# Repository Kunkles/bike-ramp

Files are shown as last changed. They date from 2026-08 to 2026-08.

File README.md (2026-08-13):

# Little Ripper — Ramp Generator

**→ [Open the generator](https://kunkles.github.io/bike-ramp/)**

Printable ramps for a toddler on a balance bike — a roller hill, a step drop, or
a little curved jump — split into tiles that fit your printer bed and lock
together with drop-in dovetails.

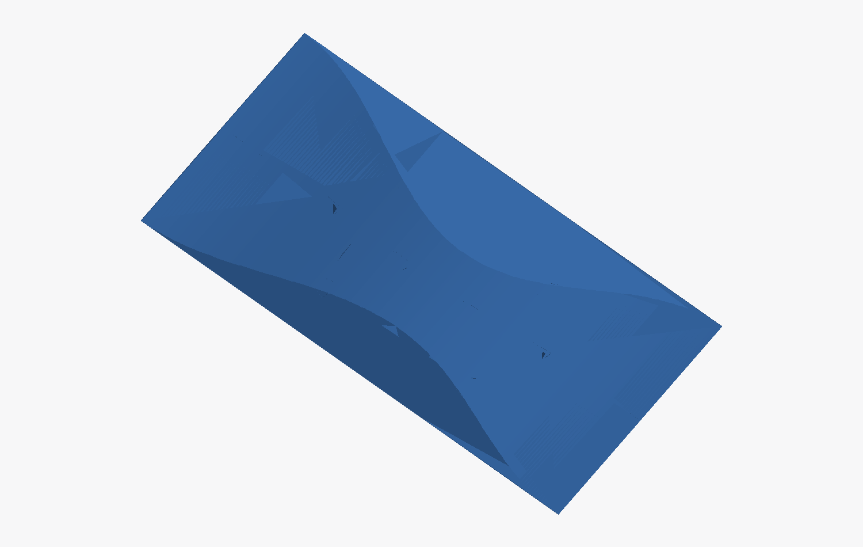
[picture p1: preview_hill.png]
assembled


**Default hill:** 600 mm long × 300 mm wide × 45 mm tall, max slope **12.9°**.
6 tiles, largest 212 × 162 × 45 mm, plus 6 screw-in ground spikes. Roughly
**1.1 kg** of filament.

The profile has zero slope at both toes and at the crest, so there is no edge to
catch a wheel and no kick at the top — he rolls on, over, and off. The outer
90 mm of each side tapers to the floor, so riding off the side is a slope rather
than a drop.

## Files

| | |
|---|---|
| `webapp/coasting-hill.html` | **the generator** — sliders, live 3D, downloads the STLs as a zip |
| `webapp/style.css` | the look: late-80s freestyle BMX, Haro teal and hot magenta |
| `bikeramp.scad` | the same model in OpenSCAD; every dimension is a parameter at the top |
| `render.sh` | exports all tiles to `stl/` |
| `stl/tile_IJ.stl` | the default hill **without** spike sockets — also the test fixture. `I` = position along the run (0…2), `J` = across the width (0…1) |
| `docs/index.html` | the same app as a standalone page, served by GitHub Pages |
| `testplate/` | a one-plate test print with full-size joints — do this first |
| `stlinfo.py` | bounding box + filament estimate for exported STLs |
| `preview.py` | renders the STLs to a PNG |
| `webapp/geom.js` | the model reimplemented as a mesh generator, shared by the app and the tests |
| `webapp/test.js` | checks the mesher against OpenSCAD and proves every tile is watertight |
| `webapp/build.py` | inlines everything into the single-file app |

## The generator

Live at **[kunkles.github.io/bike-ramp](https://kunkles.github.io/bike-ramp/)**,
or open `docs/index.html` straight from disk — it is one self-contained file
with no dependencies, no server and no install. Pick your printer from the
dropdown, drag the sliders, and it
re-tiles live — showing tile count, largest tile against your bed, max slope,
filament and print time — then hands you a zip of STLs plus a README and a
matching `.scad`.

```bash
open webapp/coasting-hill.html
```

Rebuild it after editing anything under `webapp/`:

```bash
python3 webapp/build.py
```

## Or straight from OpenSCAD

STLs for the default hill are already in `stl/`. To re-render with changes:

```bash
./render.sh -D hill_height=70 -D hill_length=800
```

## Print the test plate first

[`testplate/`](testplate/) is a 180 × 160 × 30 mm hill that splits into two
tiles fitting a **single plate** — ~163 g, about 5 h. It is small but nothing on
it is scaled: the dovetail and thread clearances are the production values, so
it answers the two questions that actually matter before you commit a day of
printing. Does a tile drop onto its neighbour, and does a spike wind into its
socket? See [testplate/README.md](testplate/README.md).

## Printing

Six plates, one tile each. **Slice `tile_10.stl` first** — it's the tallest and
most expensive; its real time and weight tell you what the whole set costs.

| Setting | Value |
|---|---|
| Material | **PLA indoors. PETG or ASA if it ever lives in a garage, car, or sun** |
| Layer height | 0.28 mm (0.4 nozzle) |
| Wall loops | 3 |
| Top / bottom shells | **10 top**, 4 bottom |
| Infill | **25% gyroid** |
| Supports | none — every tile prints flat side down, no overhangs |
| Brim | yes, ~5 mm |

**Why 10 top layers and 25% infill.** The low end of the ramp is a nearly flat
surface sitting over sparse infill, which is the classic case for pinholes in
the top skin — it sags between infill lines before it closes. This is a slicing
symptom, not a hole in the model: the mesh there is solid and closed. 25% infill
puts a support roughly every 1.7 mm instead of 2.8 mm, and 10 top layers give
the skin 2.8 mm to close in. Turn on *Ensure vertical shell thickness* as well.
If it still shows, drop to 0.2 mm layers — the surface is shallow, so thinner
layers put far more material under the skin per millimetre of run.

Raising **Toe thickness** does *not* fix this, and slightly works against it: a
thicker toe shrinks the zone that is thin enough to print 100% solid, exposing
more of the shallow curve to sparse infill. It is there for edge durability.

The PLA warning is the one that matters. PLA starts going soft around 55–60 °C
and a hill sitting in a sunny garage or the back of a car will sag out of shape.
Indoors it's fine.

Why those shells: a 15 kg kid plus bike landing on one wheel is roughly 250 N on
a contact patch around 150 mm², about 1.7 MPa. Gyroid at 15% carries that with
around 4× margin, and 6 top layers (1.7 mm) keeps the surface from dimpling
between infill cells. Dropping to 10% infill saves ~150 g and is still fine for
a toddler; go to 20% if he's on the bigger side or you want it to survive adults
standing on it.

Print time is extruded volume divided by an average throughput, plus 6 minutes
a plate for heat-up, levelling and purge. That throughput is the one number
carrying your printer, and the app sets it from whichever you pick — roughly
11 mm³/s for an X1C, 12 for an H2S, 8 for a MK4, 4 for a stock Ender 3. So the
default hill lands near 26 h on an X1C, 22 h on an H2S and 71 h on an Ender 3.

Those are class figures, not measurements. **Slice one plate, then nudge
*Average flow* until the app's time matches** — every later estimate follows
from it.

## Assembly

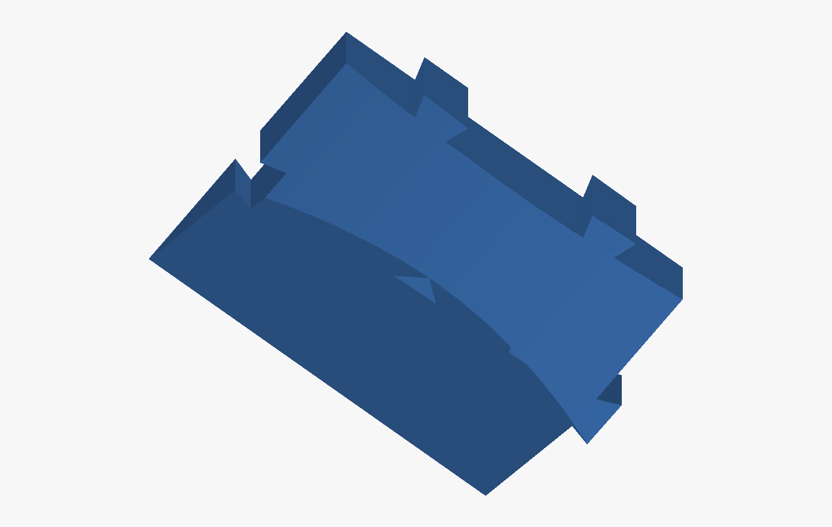
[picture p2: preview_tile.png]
tile


Tiles drop straight down into place; the dovetails are plan-view only, so any
tile can go in at any time and nothing needs sliding. Lay them out 3 along the
run × 2 across, matching the `tile_IJ` numbering, and press the seams together.
Sockets are cut with **0.20 mm** clearance per side, so 0.4 mm of play across
each dovetail. These are plan-view joints — assembly is straight down and the
flanks never slide against each other — so the clearance is there to absorb
print error, mostly first-layer squish on the tab, not to make the parts go
together. 0.35 mm proved loose enough to rattle on a test print.

If a joint binds, a pass with a knife on the socket walls is quicker than
reprinting, and turning on elephant-foot compensation helps. If it still
rattles, drop to 0.15 mm.

Label each tile as it comes off the plate. They all look similar and only one
arrangement is right.

**Stop it sliding.** The dovetails hold tiles to each other, but the assembly as
a whole will skate on a hard floor when he rides at it, and that's the thing
most likely to put him down. On carpet it's fine as-is. On hardwood, tile, or
concrete, do one of:

- stick adhesive rubber furniture pads under each tile, or
- run a bead of silicone caulk on the undersides and let it cure into feet, or
- put the whole thing on a rubber-backed rug.

Also check for a tile that rocks on an uneven floor before he rides it.

## Shapes

| | |
|---|---|
| **Roller** | Up and back down. Zero slope at both toes and at the crest, so there is nothing to catch a wheel. `humps: 2` gives a camel back. |
| **Step drop** | Rises, runs flat along a deck, then stops at a vertical edge. `hill_height` *is* the drop. |
| **Curved jump** | A circular arc tangent to the ground at the toe and steepest at the lip — so it launches — with a vertical face behind. |

The drop and the jump both finish at full height, so the far end of the last
tile is a vertical wall rather than a feathered toe. Two things follow from
that: leave clear flat run-out past the edge, and remember the back of the
thing is a wall if he rides at it the wrong way round. The side taper still
applies, so the edge is highest in the middle and falls away at the sides.

The app reports the number that matters for each: **max slope** for a roller,
the **approach** gradient for a drop, and the **takeoff** angle for a jump.

Starting points, all gentle: drop 500 × 300 × 50 with a 150 mm deck (12.4°
approach), jump 350 × 300 × 40 (12.7° takeoff, ~0.6 kg and 16 h — much cheaper
than the roller).

## Decals

Relief graphics on the side flanks — a blocky stencil word and a checkered band.
The checker is **two levels only** — squares sit ±0.6 mm either side of the
flank, proud meeting sunk directly with no strip of original surface between
them. Raising only the odd squares leaves the rest indistinguishable from the
flank, so the band has no edge; a grout line between them reads as a third
level and puts a ridge round every square.
Both flanks are laid out to read the right way round from their own side.
Type whatever you like in **Says**; A–Z, 0–9 and a few marks are supported and
anything else is dropped.

Each word gets its own line, so "LITTLE RIPPER" stacks as two. That is not just
styling: one long line has to cross the tile joints, where it gets trimmed away
and letters come out chopped. Stacked words make a block small enough to sit
inside a single tile, and the generator places it on the tallest joint-free run
of the ramp — high enough that the riding surface does not clamp it flat.

**Nothing goes on the riding surface.** Relief under a 12" wheel is a bump and a
trip edge, so decals live only on the flanks, which are already sloped and not
ridden on. That is not a convention, it is enforced by the geometry: the height
field is `min(profX, profY + relief)`, and the `min` clamps a decal to the
riding surface rather than letting it rise above.

Decals also stop short of every joint, by the seam plus a dovetail either side.
Relief on a tab or inside a socket would foul the fit, and the tiles are
separate prints with clearance anyway — a letter spanning a joint reads as
broken however it is meshed.

The letters are a 5×7 stencil so every edge is axis-aligned and lands on a mesh
grid line exactly, which is what keeps them crisp and lets OpenSCAD and the mesh
generator agree block for block.

## Multi-colour (AMS)

Tick **Separate bodies for AMS** and the download gains one thin body per decal
level — `tile_00_letters.stl`, `_checker_a`, `_checker_b` — already aligned to
the tile. Load them as parts of the tile in the slicer and assign filaments.
Use two, three or four colours; assigning two bodies the same filament costs
nothing. The preview colours each region separately, so what you see on screen
is what you would assign in the slicer — pick a region under **Filament
colours**, then a swatch.

The bodies overlap the tile rather than being cut from it, which is how slicers
expect it: overlapping parts of one object resolve in favour of the later part.
The tile itself is unchanged and still prints fine on its own.

**Watch the purge.** Decals sit on a slope, so they span ~132 layers per tile and
every one of those needs colour changes. Across the six tiles that is roughly
236 g with similar colours, ~550 g at strong contrast and over 1 kg going to
black — against a 1266 g hill. Turn on *flush into object infill*; this hill has
about 490 cm³ of infill to absorb it. Checker-only is a third the cost of the
letters, since it sits low on the flank and spans 49 layers.

From OpenSCAD: `-D 'part="body"' -D body_rel=1.2` for the letters, `0.6` for the
proud squares, and the negative value for the sunk ones.

## Ground spikes

On by default at ¼ inch; the **Underside** view in the app shows the sockets.
Each tile thick enough to take one gets a single
blind socket in its underside — a 14.6 mm twelve-sided bore, 11 mm deep, with at
least 5 mm of deck left above it — and you print one screw-in spike per socket.
The toes are only a millimetre or two thick so they get none; the dovetails tie
them to the tiles that are pegged down.

**The socket is threaded to match the spike** — the same 3 mm-pitch form pushed
out by 0.25 mm of radial clearance, so the two mate at every point rather than
the spike cutting its own groove. There is 8 mm of engagement, a plain lead-in
at the mouth to start the screw and a relief at the far end so the ceiling
closes flat. Wind one in by the hex flange until it meets the tile; they unscrew
again for indoor use.

Print the spikes stud-down exactly as oriented, no supports, 4 walls and 40%
infill; they're 1–2 g each. With spikes fitted the hill stands about 3 mm off
the ground.

Making that thread work meant lofting the socket wall rather than extruding it:
a helix is not a height field, but the bore radius can follow one if each rim
point is pushed along its own radius, and that offset is zero at both plain ends
so the rim and ceiling still land exactly on the plan polygon. The tile stays a
single closed body.

Spike length is ¼, ½ or 1 inch (6 / 13 / 25 mm). ¼ inch is plenty for lawn.
Set it to **None** for a flat underside with no sockets at all — but the socket
is a small blind hole in a part you are printing anyway, so leaving it in keeps
the option open.

## Changing the shape

| Parameter | Default | Notes |
|---|---|---|
| `shape` | `"roller"` | `"roller"`, `"drop"` or `"kicker"` |
| `deck` | 150 | drop only: flat run before the edge |
| `hill_length` | 600 | longer = gentler |
| `hill_width` | 300 | |
| `hill_height` | 45 | |
| `humps` | 1 | roller only. 2 gives a camel back — lengthen to match or it gets steep |
| `bevel_run` | 90 | side taper. 0 = vertical sides (don't, for a toddler) |
| `edge_lip` | 1.2 | thickness at the toe. Keeps it printable instead of a 0 mm feather |
| `bed_x` / `bed_y` | 250 / 250 | usable bed. Tiling is computed from these |
| `fit` | 0.20 | dovetail socket clearance per side |
| `spike_len` | 0 | ground spike protrusion. 6 / 13 / 25 for ¼ / ½ / 1 inch |
| `grip_depth` | 0 | try 0.6 for shallow traction grooves across the surface |

Beds are often oblong — a MK4 is 250 × 210 — so the tile grid is laid out both
ways round and whichever needs fewer plates wins. A tile that only fits turned
is flagged in the app.

The app's printer list covers Bambu (X1C/X1E/P1S/P1P, A1, A1 mini, H2S, H2D and
H2D Pro), Prusa (MK4S/MK4/MK3S+, MINI+, XL), Creality (Ender 3, K1, K1 Max) and
a Voron 350, and takes 6 mm off each axis for edge margin. Anything else, type
the numbers in.

For the **H2D and H2D Pro** the figures used are the *single-nozzle* printable
area, 325 × 320. The headline 350 mm plate width only applies with both nozzles
loaded with the same filament, which is not how you would run these tiles. The
**H2S** is single-nozzle by design, so its 340 × 320 stands. Either one prints
the default hill in **two tiles instead of six**.

`render.sh` echoes the shape and its steepest gradient for whatever you set.
Some starting points:

```bash
./render.sh -D hill_height=70 -D hill_length=800     # 15.1°, 8 tiles, taller
./render.sh -D humps=2 -D hill_length=1000 -D hill_height=50   # 17.0°, camel back, 10 tiles
./render.sh -D 'shape="drop"' -D hill_length=500 -D hill_height=50 -D deck=150
./render.sh -D 'shape="kicker"' -D hill_length=350 -D hill_height=40
./render.sh -D bed_x=244 -D bed_y=204                # Prusa MK4
./render.sh -D spike_len=6                           # add the spike sockets
openscad -o spike.stl -D 'part="spike"' -D spike_len=6 bikeramp.scad
```

Keep it gentle. A hill he can't get up isn't fun, and 13° is already a steep
driveway. Print the default, watch him ride it, then decide whether to go bigger.

## Mesh accuracy

The riding surface is `min(profX, profY)`, so it **folds** along the curve where
the two are equal — the join between the riding face and the side taper. A flat
facet cannot span a fold, and because the fold runs diagonally to the mesh grid
it came out visibly serrated: over a millimetre out on the default hill, nearly
two on a short steep one. Refining the grid barely helped, because a crease is
not curvature.

Cells straddling the fold are now split along it, the same way they are already
split along dovetail edges, so each half sits on one smooth branch. The cut
point on a shared edge is interpolated from that edge alone, so the neighbouring
cell computes the same point and the surface stays closed. Worst-case error went
from 1.32 mm to 0.017 mm on the default hill, for about the same triangle count
— and agreement with OpenSCAD, which does exact CSG and never had the problem,
tightened from ~0.05% to ~0.01%.

Cell size also follows the profile now: a flat facet sags by roughly
`h″·cell²/8`, so the mesh picks its own spacing from the sharpest curvature to
hold 0.05 mm. Long gentle hills stay coarse and fast; short steep ones refine
themselves.

## What's been checked

Geometry only — nothing here has been printed or ridden.

- Every tile fits the X1C bed (largest 212 × 162 × 45 mm).
- The six tiles sum to 4.81 cm³ *less* than the uncut hill, which matches the
  calculated dovetail clearance volume (4.79 cm³) to within 0.5% — so the tabs
  and sockets are complementary, correctly placed, and nowhere overlapping.
- The riding surface is continuous across every seam, and follows the height
  field to within 0.05 mm across eight shapes including the fold at the side
  taper (`node webapp/test.js`, section 5).
- Every tile is **manifold**, not merely closed: each undirected edge is shared
  by exactly two faces, across 17 configurations. Edge-cancellation alone — what
  the suite checked before — passes meshes where four faces meet on one edge,
  which is what zero-area triangles and corner-touching decal blocks produce.
  Adding that check found and fixed 60 such edges around the spike sockets that
  had been passing as watertight.
- No decal rises above the riding surface, and none overlaps a dovetail.
- The generator's mesher agrees with OpenSCAD to within 0.15% on every tile
  (0.06% with spike sockets, 0.05% on the drop and the jump, 0.21% on the spike
  itself), and its exported STLs stay manifold after rounding to float32
  (`node webapp/test.js`).
- All three shapes stay watertight, including the vertical end face, across
  extremes of height, deck length and zero side taper.
- Spike sockets keep every tile watertight, and the volume they remove
  converges on the analytic threaded bore as the mesh is refined (1.6% at the
  default 8 mm cell, 0.2% at 1.5 mm — the residue is surface discretisation,
  not the socket).
- Spike and socket are sampled against each other over the whole engaged band:
  the radial gap is 0.250 mm everywhere, to within floating point. A sign or
  amplitude slip in either thread would still print and still be watertight, and
  simply not screw together — so this is checked directly rather than inferred.

The shell/infill and print-time numbers above are analytical, not measured.
Per-printer throughput figures are rough classes; the app exposes the number so
you can correct it from a real slice.

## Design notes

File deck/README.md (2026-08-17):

# Plywood deck ramp — v3

A 1100 × 250 mm ramp, two humps, 35 mm tall: a printed frame with the plywood
deck **slid into a groove down each edge**. No screws, no drilling.

|  | printed | time |
|---|---|---|
| this | **1.19 kg** | **~24 h** |
| same ramp printed solid | 2.29 kg | 48 h |

## How the sheet is held

It slides in from one end, like a drawer. Each edge channel carries a groove at
deck height; the sheet runs 8 mm into each side, so it is wider than the gap
between the channels and cannot lift out.

That replaces v2's "drill a pilot through the ply and into a 12 mm printed edge,
three times per rib". Screws into PLA work once and strip on the second go, and
the whole point of this thing is that a five-year-old ramp should come apart and
go back together.

The channels also cap the exposed plywood edges, which were a known limit in v1
and v2.

**Slot height is 3.7 mm for a 3.18 mm sheet — 0.5 mm of slip.** Nominal 1/8"
plywood varies. Measure yours before printing 10 channel segments: anything over
3.7 mm will not go in.

## Why this geometry

**Hump spacing is 550 mm because that is the Strider 12's wheelbase.** Both
wheels crest together and the whole bike lifts, so he feels ~97% of the 35 mm. A
single 600 mm hump gives only half its height — when the front wheel is on the
crest the rear is still on flat ground.

**Don't stretch to 1100 mm humps.** At twice the wheelbase one wheel sits in a
trough while the other is on a crest, they cancel, and it feels flat.

**Ribs are 91.7 mm apart** — inside the 108 mm limit for 1/8" ply to stay under
2 mm sag at a 200 N wheel load, and placed so a rib lands on each crest.

## Parts — 42 in total

| file | what | qty |
|---|---|---|
| `rib_00` … `rib_05` | cross ribs, all different heights | 6 |
| `base_0a` … `base_7c` | base ladder, three lines | 24 |
| `channel_0L` … `channel_4R` | edge channels, the sheet slides in these | 10 |
| `threshold_x2` | end run-ups | **2** |

Ribs are **not** interchangeable. Print them standing on edge as oriented; base
strips and channels print flat. 3 walls, 25% gyroid, 6 top layers — none of
these is a riding surface.

## Plywood

One piece, **1100 × 234 mm**, 1/8" (3.2 mm), grain along the length.

Note the 234: it is *not* the ramp width. The sheet is narrower than the ramp
overall and wider than the gap between the channels, because it sits 8 mm inside
each groove. The generator's cut list gives the exact number for your settings.

## Assembly

1. Lay the base strips end to end in three lines.
2. Drop each rib's feet into its mortises. Stations from one end (mm):
   **183, 275, 367, 733, 825, 917** — tallest at 275 and 825. There is no rib
   between 367 and 733; that is the middle trough, where the deck comes down on
   the base ladder.
3. Set a channel run down each edge, grooves facing in.
4. **Feed the sheet in from the low end and push.** It bends as it goes; that is
   expected. If it binds, ease the leading corners with sandpaper — don't force
   it.
5. Butt a threshold against each end, outside the ramp.

## Check before he rides it

1. **Stand on a crest.** More than ~3 mm sag means thin ply or a rib not seated.
2. **Every rib bearing** — no rattle when you press between ribs.
3. **No step at either threshold.** The deck sits 9.2 mm up; each threshold
   climbs that over an 80 mm run. This is the one place a wheel can catch.
4. **Sheet fully home at both ends**, not standing proud of a channel.

## Joining modules

Set the shape to **Module: up / flat / down** and the frame gains a joint at each
end where the ramp is at full height.

The base strips stop with a **half-mortise** at the module face. Butt two
modules and the two halves make a whole mortise; one rib's feet drop into it and
span the seam, tying the modules together. That same rib carries the end of both
plywood sheets, so the riding surface stays flush across the joint.

Both modules ship a rib for the shared station and they are identical, so **use
either one and keep the spare** — you get one spare rib per joint.

The channels butt end to end. They sit on the ground and the shared rib holds
them in line, so there is nothing to fasten.

**A roller will not join anything.** It returns to the ground at both ends, so
there is no full-height face to mate with. Use up / flat / down for anything you
intend to extend later.

## Getting it onto the printer

**Download project .3mf** is the one you want: every plate in a single Bambu
Studio project, parts arranged in the bed, named, in millimetres. Open it and
all the plates are there.

**Plates separately .zip** gives one plain 3MF per plate instead — only what the
3MF spec defines, so it opens in any slicer.

**Download all tiles .zip** still gives individual STLs to arrange by hand.

Plates leave the X1C's 18 x 28 mm front-left exclusion clear, and by default
also reserve the 35 mm purge / flow-calibration square. Turn **Purge area** off
in the viewport if you are printing one colour and skipping calibration -- it
costs about one extra plate on a deck build.

None of them carry print settings, so set walls / top layers / infill yourself
the first time. For a deck build nothing you print is a riding surface, so a
coarse layer height costs you nothing: 0.28 mm rather than 0.12 roughly halves
the time.

## Known limits

- **Untested in plastic.** Rib spacing comes from a beam calculation assuming
  9 GPa plywood and a 200 N wheel load. Garage ply varies.
- **The slide-in fit is unproven.** 0.5 mm of slip over a 1100 mm curved run is
  a guess. Print **one channel segment and one rib**, and try a plywood offcut
  in it before printing the other nine.
- **No ground spikes.** On grass, stake the thresholds.
- Generated from `webapp/deck.js`; the solid path has an OpenSCAD cross-check
  and this does not.
- The per-plate 3MF is confirmed: Bambu Studio opened it, kept the object names,
  and saved back all 52,956 triangles unchanged. The **single-file project** is
  newer and has not been through Studio yet -- the plate schema came from a
  project Studio saved, but the plate grid stride (bed + 57 mm) is the one
  measured constant in it.
- **The module joint is untested in plastic.** It resists the modules sliding
  apart and keeps them level, but nothing stops a determined lift. If it works
  loose in use, a strap or a stake through the end thresholds will hold it.

## Wider than your bed

A rib spans between the channels and prints standing on edge, so its footprint
is as long as the ramp is wide. Past the bed it is cut over the centre of a base
strip, where the mortise holds both halves. Those parts are named `rib_00a`,
`rib_00b`. Base strips and channels are cut to the bed the same way, so all
three follow whichever printer is selected in the generator.

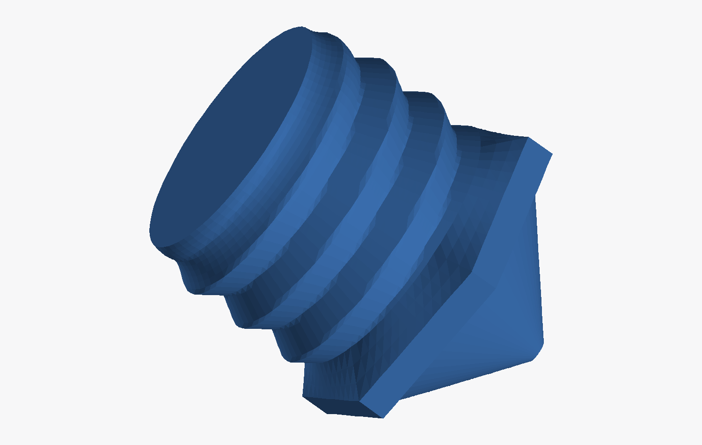
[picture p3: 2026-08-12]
preview_spike.png

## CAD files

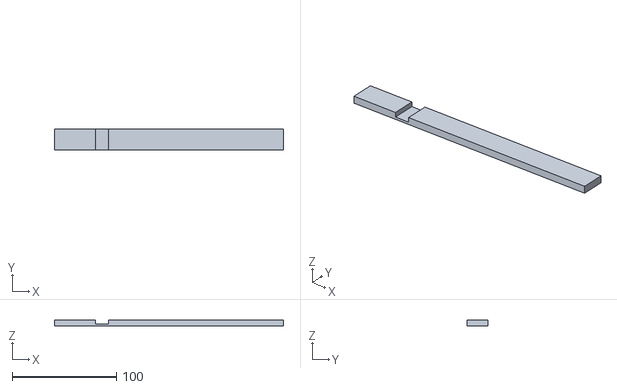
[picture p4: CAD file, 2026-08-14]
deck/base_2c.stl
220.0 x 20.0 x 6.00

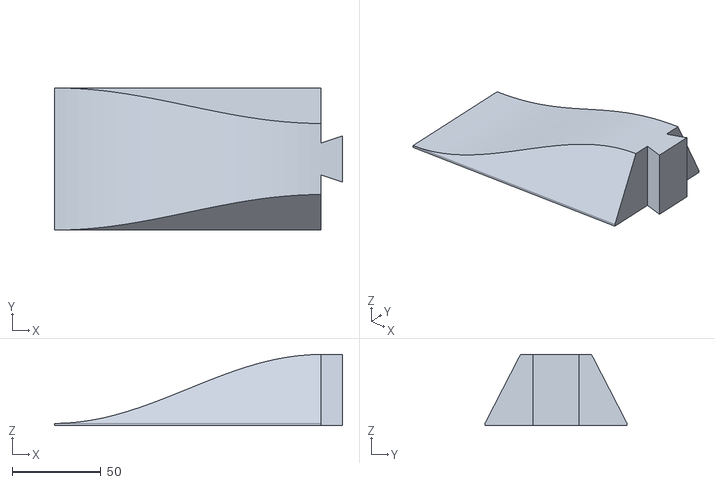
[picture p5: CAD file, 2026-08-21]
modules-test/module_up.stl
162.0 x 80.0 x 40.0

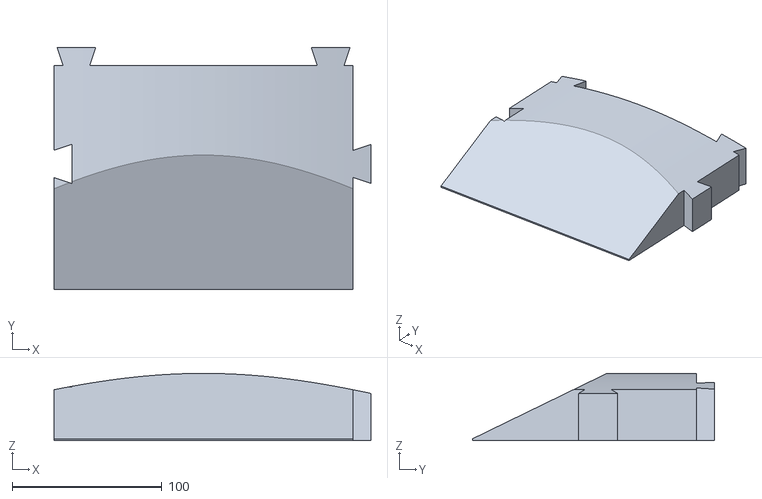
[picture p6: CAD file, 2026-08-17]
stl/tile_10.stl
212.0 x 162.0 x 45.0

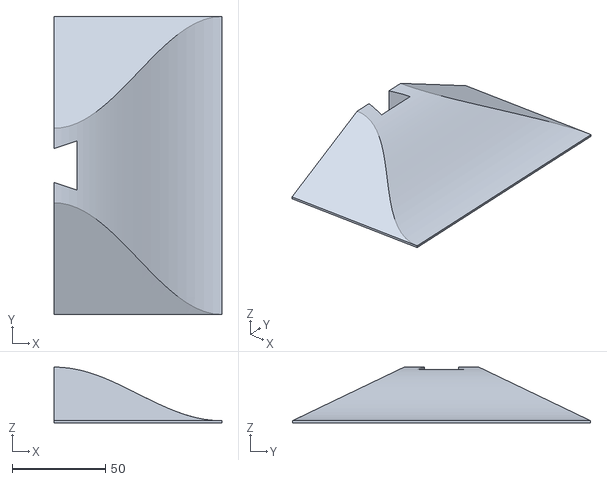
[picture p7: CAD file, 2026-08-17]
testplate/tile_10.stl
90.0 x 160.0 x 30.0

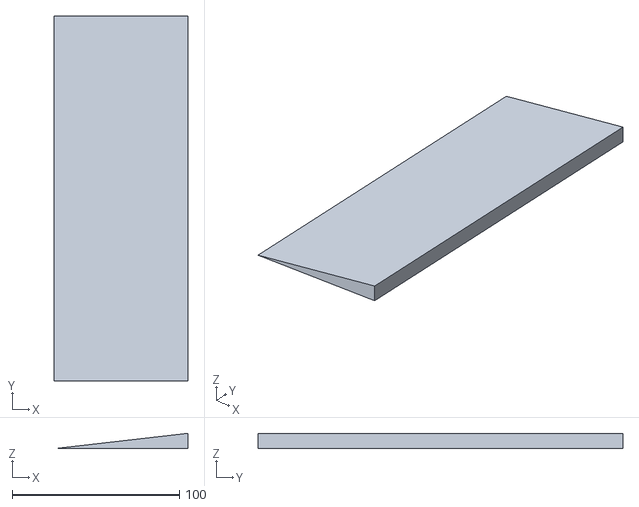
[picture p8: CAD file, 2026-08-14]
deck/threshold_x2.stl
80.0 x 218.0 x 9.18

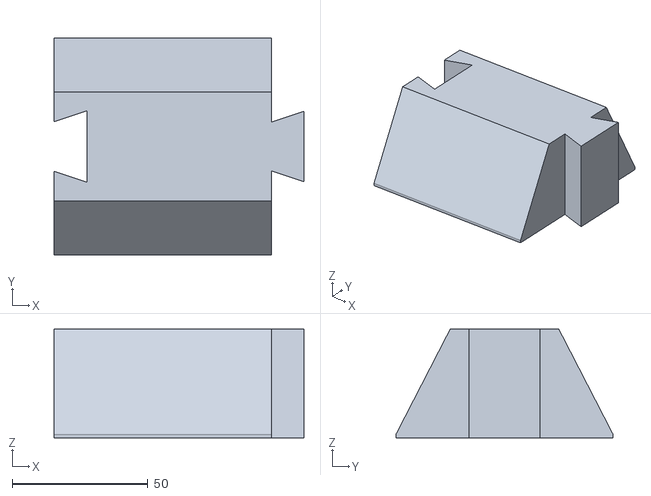
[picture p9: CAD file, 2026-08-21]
modules-test/module_flat.stl
92.0 x 80.0 x 40.0

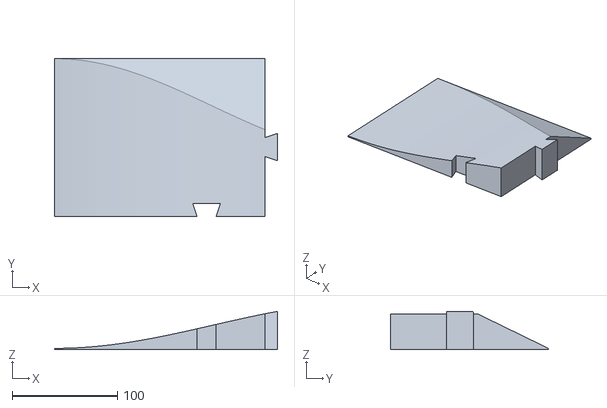
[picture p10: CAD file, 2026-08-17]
stl/tile_01.stl
212.0 x 150.0 x 36.3

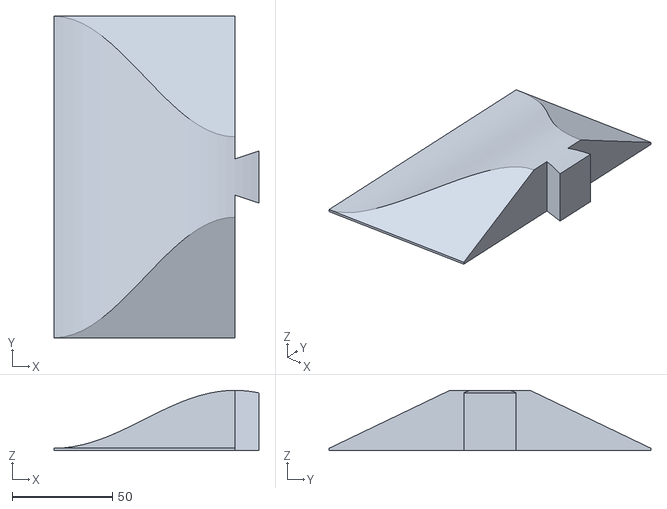
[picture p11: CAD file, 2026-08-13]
testplate/tile_00.stl
102.0 x 160.0 x 30.0

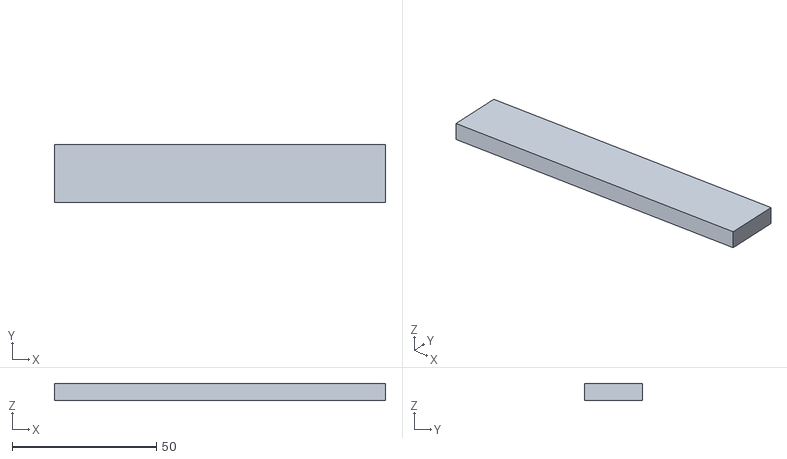
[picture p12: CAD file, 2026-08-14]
deck/base_3a.stl
114.6 x 20.0 x 6.00

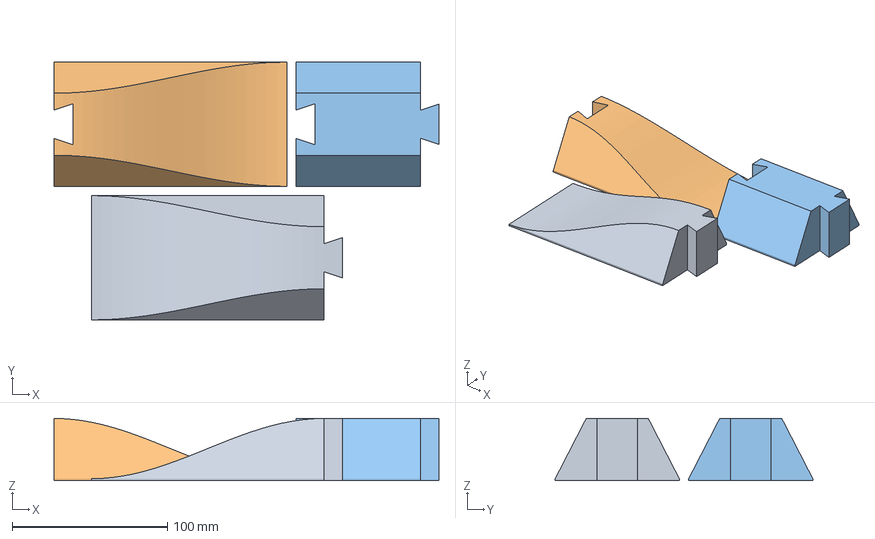
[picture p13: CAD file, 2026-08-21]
modules-test/modules_test_one_plate.3mf
248.0 x 166.0 x 40.0 mm
module_up
module_down
module_flat

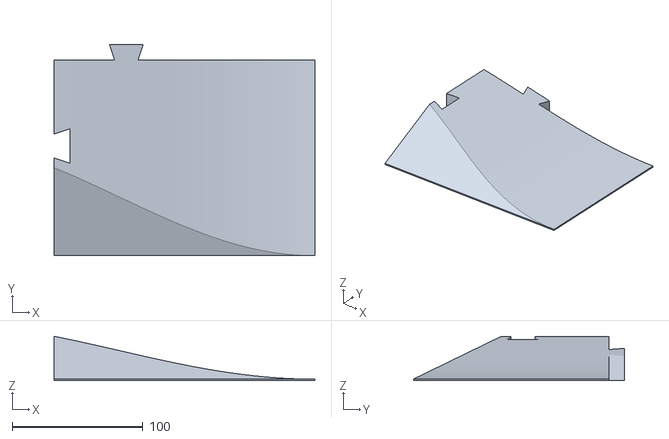
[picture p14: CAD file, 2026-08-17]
stl/tile_20.stl
200.0 x 162.0 x 34.0

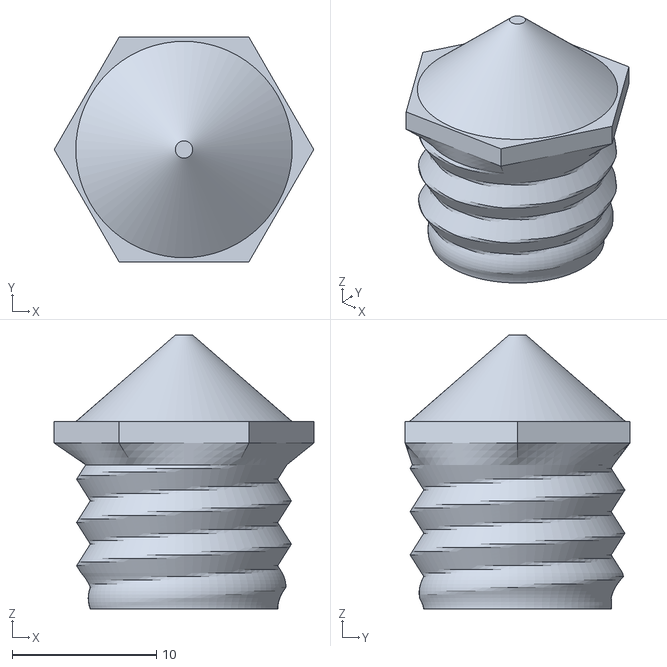
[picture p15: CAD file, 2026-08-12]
testplate/spike.stl
18.0 x 15.6 x 19.0

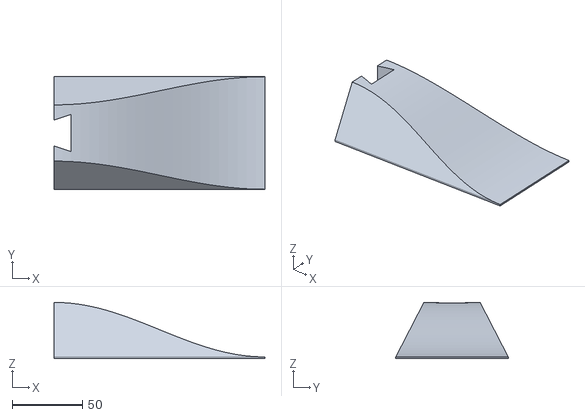
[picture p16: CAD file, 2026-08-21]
modules-test/module_down.stl
150.0 x 80.0 x 40.0

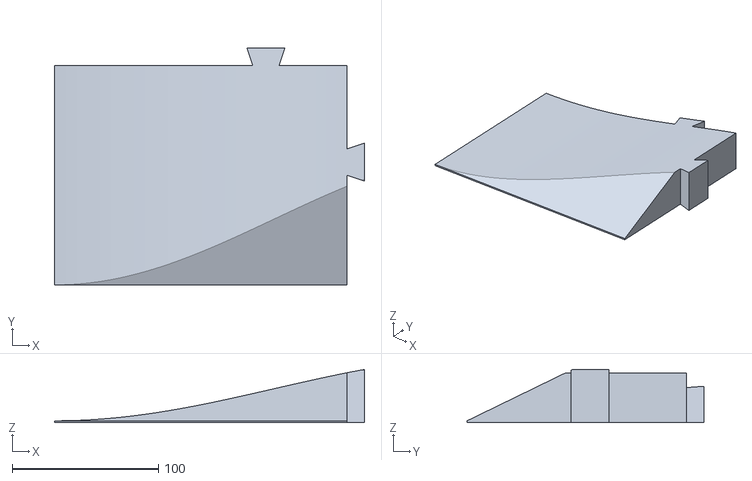
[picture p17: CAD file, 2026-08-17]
stl/tile_00.stl
212.0 x 162.0 x 36.3

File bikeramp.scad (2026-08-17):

// ============================================================================
//  bikeramp.scad  --  printable coasting hill for a toddler balance bike
//
//  Generates a smooth cosine "roller" hill, auto-split into bed-sized tiles
//  that lock together with drop-in dovetails.
//
//  Render one tile:   openscad -D 'part="tile"' -D tile_i=0 -D tile_j=0 -o t.stl bikeramp.scad
//  Preview the hill:  openscad -D 'part="hill"' bikeramp.scad
//  See ./render.sh for batch export.
// ============================================================================

/* [Hill] */
shape       = "roller";  // "roller" = up and back down; "rise"/"flat"/"fall" are joinable modules
                         // "drop"   = rise, flat deck, then a vertical step off
                         // "kicker" = curved launch, steepest at the lip
deck        = 150;   // drop only: flat run before the edge (mm)
hill_length = 600;   // total run, front toe to back toe (mm)
hill_width  = 300;   // riding width (mm)
hill_height = 45;    // crest height (mm)
humps       = 1;     // 1 = single hill, 2 = camel back, ...
crest_flat  = 0;     // roller only: flat run held at each crest (mm)
bevel_run   = 90;    // side taper: outer this-many mm slope down to the floor. 0 = vertical sides
edge_lip    = 1.2;   // thickness at the toe and outer edges. Raising it makes the edge
                     // sturdier but shrinks the fully-solid zone near the toe

/* [Printer] */
bed_x       = 250;   // usable bed along the run.   X1C is 256; 250 leaves margin
bed_y       = 250;   // usable bed across the width. A MK4 would be 244 x 204

/* [Joints] */
tab_depth   = 12;
tab_neck    = 18;    // width where the dovetail meets the tile (narrow)
tab_tip     = 26;    // width at the tip (wide -> locks)
fit         = 0.12;  // clearance cut into the matching socket, per side. These are
                     // drop-in joints, so this is for print error, not for sliding
min_tab_h   = 10;    // skip dovetails where the hill is shorter than this

/* [Ground spikes] */
spike_len     = 0;    // spike protrusion below the tile, mm. 0 = no sockets at all
socket_depth  = 11;
socket_roof   = 5;    // material left between socket ceiling and riding surface
socket_gon    = 24;
spike_clear   = 0.25; // radial clearance, spike to socket
thread_lead   = 1.5;  // plain bore at the mouth, to start the screw
thread_relief = 1.5;  // plain bore at the far end, so the ceiling closes flat
spike_inset   = 30;   // keep sockets clear of tile edges and their dovetails
spike_scan    = 10;   // grid the tile is searched on for its thickest point
spike_minor   = 6.5;  // thread core radius
spike_major   = 7.45; // thread crest radius
spike_pitch   = 3.0;
spike_stud    = 10;
spike_chamfer = 1.5;
spike_flange_r= 9.0;  // hex flange, circumradius. Grip it to screw the spike in
spike_flange_h= 1.5;
spike_cone_r  = 7.5;
spike_tip_r   = 0.6;

/* [Decals] */
decal        = "none";  // "none" | "text" | "checker" | "both"
decal_text   = "LITTLE RIPPER";
decal_relief = 1.2;     // how far the decal stands proud of the flank (mm)

/* [Grip] */
grip_depth  = 0;     // 0 = smooth. 0.6 gives shallow traction grooves
grip_pitch  = 14;
grip_width  = 4;

/* [Output] */
part      = "tile";  // "tile" | "hill" | "mono" | "spike" | "body"
body_rel  = 0;       // "body": which relief level to skin, for multi-material
body_skin = 0.9;     // how deep that skin runs
tile_i = 0;          // tile index along the run
tile_j = 0;          // tile index across the width

/* [Hidden] */
$fn = 32;
STEPS = 160;         // profile resolution
BIG   = 1000;

// ---------------------------------------------------------------- tiling ----
// Tiles carry a dovetail past their nominal pitch, so the printable span is the
// bed less one tab. Beds are often oblong, so lay the grid out both ways round
// and keep whichever needs fewer plates.
bx = max(1, bed_x - tab_depth);
by = max(1, bed_y - tab_depth);
nx_a = max(1, ceil(hill_length / bx));  ny_a = max(1, ceil(hill_width / by));
nx_b = max(1, ceil(hill_length / by));  ny_b = max(1, ceil(hill_width / bx));
turned = nx_b * ny_b < nx_a * ny_a;

nx = turned ? nx_b : nx_a;
ny = turned ? ny_b : ny_a;
px = hill_length / nx;   // tile pitch along the run
py = hill_width  / ny;   // tile pitch across the width

// ---------------------------------------------------------------- profile ---
// Three lengthwise profiles. "roller" returns to the ground; "drop" and
// "kicker" both finish at full height, so the far end is a vertical face.
function prof_x(x) =
    let (h = hill_height - edge_lip, L = hill_length)
    shape == "drop"
      ? let (rise = max(1, L - min(deck, L * 0.8)))
        (x >= rise ? hill_height
                   : edge_lip + h * 0.5 * (1 - cos(180 * min(1, max(0, x / rise)))))
  : shape == "kicker"
      ? (h < 0.01 ? edge_lip
         : let (R = (L * L + h * h) / (2 * h), xx = min(max(x, 0), L))
           edge_lip + R - sqrt(max(0, R * R - xx * xx)))
  : shape == "flat" ? hill_height
  : (shape == "rise" || shape == "fall")
      ? // Half a raised cosine: leaves the ground and arrives at full height
        // with zero slope at both ends, so any two modules butt together
        // without a kink in the riding surface.
        let (tm = min(1, max(0, x / L)), c2 = cos(180 * tm))
        edge_lip + h * 0.5 * (shape == "rise" ? 1 - c2 : 1 + c2)
  : // Roller: a raised cosine, optionally held at its peak for a flat top.
    let (lam = L / max(1, humps),
         c = min(max(0, crest_flat), lam * 0.8),
         w = lam - c,
         u = x - floor(x / lam) * lam,
         ue = u < w / 2 ? u : (u > w / 2 + c ? u - c : w / 2))
    edge_lip + h / 2 * (1 - cos(360 * ue / w));

// Steepest gradient the rider meets: the lip on a kicker, the approach on a drop.
function max_slope() =
    let (h = hill_height - edge_lip, L = hill_length)
    shape == "drop"   ? atan(PI * h / (2 * max(1, L - min(deck, L * 0.8))))
  : shape == "kicker" ? (h < 0.01 ? 0
                         : let (R = (L * L + h * h) / (2 * h))
                           atan(L / max(1e-9, R - h)))
  : shape == "flat" ? 0
  : (shape == "rise" || shape == "fall") ? atan(PI * h / (2 * max(1, L)))
  : // the cosine is squeezed into (wavelength - flat), so it steepens
    let (lam = L / max(1, humps), c = min(max(0, crest_flat), lam * 0.8))
    atan(PI * h / max(1e-9, lam - c));

// Crosswise: flat in the middle, tapering to the floor over bevel_run.
function prof_y(y) =
    bevel_run <= 0
      ? hill_height
      : edge_lip + (hill_height - edge_lip)
          * min(1, max(0, min(y, hill_width - y) / bevel_run));

function h_at(x, y) = min(prof_x(x), prof_y(y));

// ------------------------------------------------------------ hill solid ----
// The lengthwise sweep is floored at z=0, so it alone bounds the solid below.
// The crosswise sweep runs well below zero, which lets it be raised by the
// decal relief without lifting the underside off the bed.
module sweep_x() {
    translate([0, hill_width + BIG, 0])
        rotate([90, 0, 0])
            linear_extrude(hill_width + 2 * BIG)
                polygon(concat(
                    [[0, 0]],
                    [for (i = [0 : STEPS])
                        let (x = i * hill_length / STEPS) [x, prof_x(x)]],
                    [[hill_length, 0]]
                ));
}
module sweep_y() {
    translate([-BIG, 0, 0])
        rotate([0, 0, 90]) rotate([90, 0, 0])
            linear_extrude(hill_length + 2 * BIG)
                polygon(concat(
                    [[0, -BIG]],
                    [for (i = [0 : STEPS])
                        let (y = i * hill_width / STEPS) [y, prof_y(y)]],
                    [[hill_width, -BIG]]
                ));
}
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

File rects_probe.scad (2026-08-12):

include <bikeramp.scad>
echo(str("SCAD_N=", len(decal_rects())));
echo(str("SCAD_SUM=", [for(r=decal_rects()) (r[2]-r[0])*(r[3]-r[1])]));

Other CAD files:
deck/base_0c.stl
deck/base_6a.stl
stl/tile_11.stl
deck/base_0a.stl
deck/base_0b.stl
deck/base_1a.stl
deck/base_1b.stl
deck/base_1c.stl
deck/base_4a.stl
deck/base_4b.stl
deck/base_4c.stl
deck/base_5a.stl
deck/base_5b.stl
deck/base_5c.stl
deck/base_6b.stl
deck/base_6c.stl
deck/channel_0L.stl
deck/channel_0R.stl
deck/channel_1L.stl
deck/channel_1R.stl
deck/channel_2L.stl
deck/channel_2R.stl
deck/channel_3L.stl
deck/channel_3R.stl
deck/channel_4L.stl
deck/channel_4R.stl
deck/rib_00.stl
deck/rib_01.stl
deck/rib_02.stl
deck/rib_03.stl
deck/rib_04.stl
deck/rib_05.stl
stl/tile_21.stl

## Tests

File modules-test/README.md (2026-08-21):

# Module joint test — one plate

`module_up` + `module_flat` + `module_down`, 80 mm wide and 40 mm tall, on a
single 250 × 250 plate. About 317 g and 6.5 h total.

## These are small, not scaled

Nothing here is shrunk. **The dovetail is the production part at production
size** — 12 mm deep, 26 mm at the tip, 0.12 mm clearance per side. Only the ramp
around it is short.

That distinction is the whole point. Scaling a module down 3× would scale the
clearance to 0.04 mm, which is under one extrusion width: the joint would fuse
solid and tell you nothing about whether the real one fits. A short ramp with a
full-size joint tells you exactly what a long one would.

Each joint here gets **one** dovetail because the modules are 80 mm wide. At your
330 mm working width the same joint gets three. One is the harder test — all the
load goes through it.

| file | size | weight |
|---|---|---|
| `module_up.stl` | 162 × 80 × 40 mm | ~117 g |
| `module_flat.stl` | 92 × 80 × 40 mm | ~92 g |
| `module_down.stl` | 150 × 80 × 40 mm | ~108 g |

`modules_test_one_plate.3mf` has all three arranged, clear of the wipe patch and
the purge square.

## Slice it like the real thing

0.28 mm layers, **3 walls**, 10 top / 4 bottom, 25% gyroid, no supports, 5 mm
brim. The clearance is what you are testing, so do not change flow or horizontal
expansion from whatever you will use on the real ramp.

## What to check

1. **Does `module_flat` drop onto `module_up` without forcing?** Straight down,
   not slid. Snug is right; a mallet is not.
2. **Take it apart and put it back.** Twice. This joint exists so the ramp can be
   dismantled for storage — if it only goes together once, that has failed.
3. **Press down on the seam.** Any hinge or step where the two surfaces meet?
4. **Assemble all three** (380 mm long) and run a finger along the top. The
   transition should be smooth — every module leaves its end at zero slope, so
   there should be no detectable kink at either joint.

If it is tight, raise **Joint clearance** 0.12 → 0.16 and reprint one piece. If
it rattles, drop to 0.10.

## Do not read the slope

At 150 mm long and 40 mm tall the approach is 22°, against 17° on the medium
ramp. That is a consequence of making it short enough to fit a plate. It is a fit
test, not a ride test.

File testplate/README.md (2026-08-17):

# Test plate — Little Ripper

One plate, full-size joints. Print this before committing to the real hill.

A 180 × 160 × 30 mm hill, deliberately small — but **nothing here is scaled**.
Every fit is the production value: 0.12 mm dovetail clearance, 0.25 mm thread
clearance, 3 mm pitch. Scaling the model would shrink those into the width of a
single extrusion and tell you nothing about whether the real parts fit.

| file | size | weight |
|---|---|---|
| `tile_00.stl` | 102 × 160 × 30 mm | ~116 g |
| `tile_10.stl` | 90 × 160 × 30 mm | ~109 g |
| `spike.stl` | 18 × 16 × 19 mm | ~2 g — print 2 |

Both tiles fit one 250 × 250 plate side by side, using 196 × 160 mm.
About 225 g and 4.7 h total on an X1C, nearer 6.5 h on a slower machine.
That is heavier than it looks for its size — 10 top layers and 25% infill
are most of it, and they are the point (see below).

## Slice it exactly like the real thing

0.28 mm layers, 3 walls, **10 top** / 4 bottom, **25% gyroid**, no supports,
5 mm brim. The high top-shell and infill matter: the low end of the ramp is
nearly flat over sparse infill and will pinhole in the skin at the usual 6/15%.
Spikes the same but 4 walls and 40% infill, printed stud-down as oriented.

## What to check

1. Does `tile_10` **drop** onto `tile_00` without forcing? There is one real
   dovetail on the seam. Snug is right; needing a mallet is not.
2. Does a spike **wind into each socket by hand, and back out again**? This is
   the least-proven part of the design.
3. Run a finger across the seam — is the riding surface continuous?
4. Do the tiles sit flat, or has a corner lifted?
5. Lean on it. 25% gyroid should not dimple under a thumb.
6. Look along the low end of the ramp in raking light. This is where the last
   print pinholed; at 10 top layers the skin should be closed.

The joint is now **0.12 mm** per side — 0.24 mm across the dovetail. It went
0.35 (loose) → 0.20 (still slightly loose) → 0.12, which should mostly close the
seam once glued while leaving a bond line for the glue to wick into.

This is the tightest it has been, so it is the thing most likely to have gone
too far. If the dovetail needs a mallet, raise **Joint clearance** to 0.16 and
reprint `tile_10` only. If a spike binds, work it in and out once to bed the
thread; Joint clearance does not affect the threads.

At 180 mm long and 30 mm tall the slope is 26.7°, twice the real hill's 12.9°.
That is fine for checking fit, surface and warp — don't read anything into how
it rides.

## Regenerating it

In the [generator](https://kunkles.github.io/bike-ramp/): Length **180**,
Width **160**, Height **30**, Side taper **60**, bed **110 × 250**, decals
**off**.

Shrinking the bed is the trick — it forces the split into two tiles so there is
a joint to test. You still print both on your real plate.

Or from OpenSCAD:

```bash
./render.sh -D hill_length=180 -D hill_width=160 -D hill_height=30 \
            -D bevel_run=60 -D spike_len=6 -D bed_x=110 -D bed_y=250
```

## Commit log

2026-08-12 Parametric coasting hill for a toddler balance bike
    A cosine roller hill, auto-split into tiles that fit the printer bed and
    lock together with drop-in dovetails, with optional screw-in ground spikes.
    Two implementations of the same model, cross-checked against each other:
    - bikeramp.scad -- the OpenSCAD source of truth.
    - webapp/geom.js -- a direct mesh generator. The tile is a height field over
    a polygonal footprint, so it needs no CSG: it meshes on a grid whose lines
    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
    [bikeramp.scad, tile_00.stl, tile_01.stl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]
2026-08-12 Add step-drop and curved-jump shapes
    Two more lengthwise profiles alongside the roller, in both implementations:
    - drop: smooth rise, flat deck, then it simply stops. hill_height is the drop.
    - kicker: circular arc tangent to the ground at the toe and steepest at the
    lip, so it launches.
    Both finish at full height, so the far end of the last tile is a vertical face
    rather than a feathered toe. That falls out of the mesher for free -- the
    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
    [bikeramp.scad]
2026-08-12 Add the Bambu H series to the printer list
    H2S at 340x320 and H2D / H2D Pro at 325x320. Both print the default hill in
    two tiles rather than six.
    The H2D figures are the single-nozzle printable area, not the 350 mm headline
    plate width -- that only applies with both nozzles loaded with the same
    filament, which is not how these tiles would be run. Printer entries can now
    carry a note, shown under the bed inputs when selected, so the caveat appears
    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
2026-08-12 Make the print-time estimate depend on the printer
    Time was extruded volume over one flat 8 mm3/s, so picking a different printer
    barely moved it -- only via the small change in seam wall area. Switching from
    an X1C to a stock Ender 3 changed the estimate by under a minute, which read as
    the number not recalculating at all.
    Throughput is now a per-printer figure, set from the dropdown and exposed as an
    editable control, plus 6 minutes a plate for heat-up, levelling and purge. The
    default hill now reads 22 h on an H2S, 26 h on an X1C, 36 h on a MK4 and 71 h
    on an Ender 3.
    The class figures are rough by nature, so the control is there to be corrected:
    slice one plate, nudge Average flow unti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
2026-08-12 Cut a real thread in the spike sockets
    The socket was a plain bore relying on the spike to form its own groove in the
    wall. Into 15% gyroid that is marginal, so the socket now carries the spike's
    own thread form pushed out by 0.25 mm of radial clearance: 3 mm pitch, 8 mm of
    engagement, a plain lead-in at the mouth to start the screw and a relief at the
    far end so the ceiling closes flat.
    A helix is not a height field, which is why this was left out before. The way
    in is to loft the socket wall instead of extruding it: push each rim point
    along its own radius by however much the thread differs from the plain bore.
    That offset is zero at both plain ends, so the rim and the ceiling still land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
    [bikeramp.scad]
2026-08-12 Add the one-plate test print
    A 180 x 160 x 30 mm hill that splits into two tiles fitting a single 250 x 250
    plate, ~163 g and about 5 h. Deliberately small, but nothing on it is scaled:
    the dovetail and thread clearances are the production values, because those are
    the two things a test print exists to check and scaling would shrink them into
    the width of one extrusion.
    [spike.stl, tile_00.stl, tile_10.stl]
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2026-08-12 Split mesh cells along the fold in the surface
    The riding surface is min(profX, profY), so it folds where the two are equal --
    the join between the riding face and the side taper. A flat facet cannot span a
    fold, and the fold runs diagonally to the grid, so it came out serrated: 1.3 mm
    out on the default hill and 1.9 mm on a short steep one. Refining the grid only
    halved it, because a crease is not curvature.
    Cells straddling the fold are now split along it, exactly as they already are
    along dovetail and socket edges. The cut point on a shared edge is interpolated
    from that edge's endpoints alone, so the neighbouring cell computes an identical
    point and the mesh stays closed. Worst error 1.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
    [tile_00.stl, tile_10.stl]
2026-08-12 Correct comments left stale by the threading and crease work
    The SPIKE block still described a plain 12-sided bore relying on the spike to
    cut its own groove, which stopped being true when the socket got a real thread.
    Two other comments had been left stacked or attached to the wrong function by
    edits, and the module header still described the simpler mesher from before
    sockets and the crease split.
2026-08-12 Rebrand as Little Ripper, late-80s BMX
    Named for what it makes and who it is for. The look is late-80s/early-90s
    freestyle rather than synthwave -- Haro teal and hot magenta, checkered flag,
    heavy italic masthead with a hard offset shadow in the second neon. Synthwave
    (purple gradients, chrome, sun grids) is the generic reading of "80s" and is
    not what a BMX magazine looked like.
    Dark mode is a night session under the lights; light mode is the number plate,
    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
2026-08-12 Raised decals on the ramp flanks
    A stencil word and a checkered band, standing proud of the side flanks. The
    text is editable, so it can say whatever you want.
    Nothing goes on the riding surface -- relief under a 12" wheel is a bump and a
    trip edge. That is enforced rather than observed: the height field becomes
    min(profX, profY + relief), so the min clamps a decal to the riding surface
    instead of letting it rise above. Decals also stop short of every joint, by the
    seam plus a dovetail either side, because relief on a tab or in a socket fouls
    the fit.
    The letters are a 5x7 stencil, so every edge is axis-aligned, lands on a mesh
    grid line, and stays crisp -- and OpenSCAD and the mesh genera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
    [bikeramp.scad, rects_probe.scad]
2026-08-12 Stack decal text one word per line
    A single line of "LITTLE RIPPER" is 435mm long on the default hill, so it
    crossed both tile joints and the joint trim chopped letters out of it. Words now
    each get their own line, which makes the block about 90mm wide -- small enough
    to sit inside one tile.
    Placement follows: the block goes on the widest joint-free run, preferring the
    tallest, and its top is held below the fold. Lettering above the fold would be
    clamped flat by the riding surface, since the height field takes the min of the
    two -- it would simply vanish rather than render wrong.
    OpenSCAD mirrors the same layout and agrees to -0.001% on a decal tile.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
    [bikeramp.scad]
2026-08-12 Checker alternates proud and sunk; fix the mirrored far flank
    Two things wrong with the decals.
    The checker only raised alternate squares, leaving the others as bare flank.
    With no contrast on the off squares the band had no edge and read as scattered
    blocks rather than a checkerboard. Squares are now embossed and debossed in
    turn, which gives the band a defined extent and real alternation. Each square
    is inset so a flat grout line runs between them: butted up, four squares meet
    at a point with alternating heights, and no surface can close that -- it opened
    480 holes on the first attempt.
    The far flank was mirrored. Blocks are held as (x, distance in from the nearer
    side) so one list serve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
    [bikeramp.scad]
2026-08-12 Checker to two levels, split either side of the flank
    The grout line between squares was a third level, so every proud square had a
    ridge round it. Squares now sit at +/-0.6mm about the flank and meet each other
    directly -- no original surface left anywhere in the band, checked by sampling.
    Butted exactly, four squares meet at a point with alternating heights, which no
    surface can close. Only the proud squares are grown, and only inward, clamped to
    the band: they bridge diagonally at each corner, hold the sunk ones apart, and
    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
    [bikeramp.scad]
2026-08-13 Separate bodies for AMS, and target the toe guidance at the skin
    Multi-colour: the download can now carry one thin body per decal level --
    letters, proud squares, sunk squares -- each a skin following the flank under
    its visible surface, aligned to the tile. They overlap the tile rather than
    being cut from it, which is how slicers expect overlapping parts of one object,
    so the tile still prints fine alone. OpenSCAD gains part="body" and agrees to
    0.01%.
    Four things went wrong building it, all now fixed:
    - The skin's underside follows a height field rather than a plane, and the
    local I added for it was named `b`, which the edge loop already uses for a
    vertex. Every bottom coordinate cam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
    [bikeramp.scad, tile_00.stl, tile_10.stl]
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2026-08-13 Tighten the dovetail clearance to 0.20 mm
    A test print came out loose. 0.35 mm per side is 0.7 mm of play across each
    dovetail, which is enough for tiles to rattle against each other.
    These are plan-view joints, so assembly is straight down and the flanks never
    slide against one another. The clearance exists to absorb print error -- mostly
    first-layer squish on the tab -- not to let the parts go together, so it can be
    much tighter than a sliding fit. 0.20 mm leaves 0.4 mm of play, which should
    seat snugly without binding on an elephant foot.
    Reference and test-plate STLs regenerated.
    [bikeramp.scad, tile_10.stl]
2026-08-13 Letter short ramps, and cost the top shell honestly
    The lettering was sized from the thinnest point of the whole joint-free run.
    On a short ramp that run reaches down to the toe, so the text sized itself out
    of existence -- nothing under 500 mm carried any lettering at all, which is
    every kicker and every test plate.
    Size it from the block's own footprint instead, centred over the tallest part
    of the run, and walk the size down until it fits. A wide block reaches towards
    the toe where the flank cannot carry it; shrinking pulls it back over the tall
    part, which makes more room, so it converges. Mirrored into decal_letters() so
    the two implementations stay in step -- checked against OpenSCAD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
    [bikeramp.scad]
2026-08-13 Add a plywood deck mode, and keep decals off the underside
    Two things, both in the viewer.
    The preview picked a surface colour by plan position alone -- regionAt(x, y),
    with no z -- so every triangle beneath a decal inherited its colour, including
    the flat underside. Looking at the model from below showed the checkers and
    lettering printed across the bottom face. The geometry was always right; 8900
    down-facing triangles were being painted. A downward face is never a decal
    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
    [rib_00.stl, rib_01.stl, rib_02.stl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]
2026-08-13 Give the deck a real frame, and a bike to size it against
    The deck was a pile of loose plates. It only became rigid once the plywood was
    screwed on, there was nothing to build against, and it asked you to drive a
    screw into an 8 mm printed edge -- which splits going in and strips the first
    time you take it apart.
    So: a base ladder. Two strips run the full length carrying a mortise under
    every rib, and each rib has matching feet. The frame stands square and holds
    its own spacing before the sheet is anywhere near it. Ribs go to 12 mm so a
    screw has material either side, and the notes now point at M4 heat-set inserts
    for anything meant to come apart twice. That costs 0.44 kg -- 0.74 against th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
    [base_0L.stl, base_0R.stl, base_1L.stl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]
2026-08-13 Flat crest option, and fix the deck's ends and exploded view
    The plywood ramp's ends did not meet the ground. The thresholds were placed
    inside the run, from 0 to 80 mm, so they sat buried under the sheet while the
    deck itself stopped at a 9 mm cliff. They belong outside it: they are the run-up
    onto the deck, not part of it. Near now spans -80 to 0 and far 1100 to 1180,
    meeting the sheet flush.
    Rollers get a flat crest. The cosine is held at its peak rather than stretched,
    so the toe shape and the character of the approach are unchanged -- the curve is
    simply squeezed into what length is left, which means a long flat steepens the
    sides. The slope readout follows, and a 200 mm flat on a 600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
    [bikeramp.scad]
2026-08-13 Ship the plywood cut list, and the base strips that were missing from it
    The deck download quietly left out the base ladder. It wrote the ribs and the
    threshold and stopped, so anyone following it would have printed a frame with
    nothing to stand it on. Found by reading the bytes of an actual generated zip
    rather than the code that writes it.
    The plywood size was only buried in README.txt, so it now gets its own file with
    the dimensions in the filename -- visible in the zip listing without opening
    anything. It carries the cut in mm and inches, the grain direction, and the
    marking layout: rib centrelines and screw lines, so the sheet can be marked up
    away from the computer.
    It also states th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
2026-08-13 Fit the deck frame to the actual bed, and add a third base strip
    Three bugs, all found from one observation that the lengthwise supports looked
    long.
    The base strips never knew the printer. deck.js carried its own hardcoded
    250 mm and the app never passed the selected bed through, so segments were cut
    for an X1C whatever machine was chosen -- 46 mm too long on an A1 mini. They now
    follow the bed: 144 mm on a mini, 321 mm on an XL.
    The ribs never fitted at all. A rib spans the whole width and prints standing on
    edge, so its footprint is as long as the ramp is wide -- 50 mm past the bed at
    the default 300 mm width, with nothing to say so. They are now cut over the
    centre of a base strip, whe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
    [base_0a.stl, base_0b.stl, base_0c.stl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]
2026-08-14 Slide the plywood into edge channels instead of screwing it down
    Drill three pilot holes per rib, into a 12 mm printed edge, and hope the PLA
    threads survive being taken apart -- that was the fussiest possible answer, and
    it was chosen because it was the easiest thing to model, not because it was
    right.
    The sheet now slides into a groove down each edge, from one end, like a drawer.
    It runs 8 mm into each side, so it is wider than the gap between the channels
    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
    [base_0a.stl, base_0b.stl, base_0c.stl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]
2026-08-17 Tighten the joint to 0.12 mm, and save the medium setting
    Measured on a real print, which beats every estimate here: 0.35 was loose, 0.20
    was still slightly loose. 0.12 puts 0.24 mm across the dovetail -- enough of a
    bond line for glue to wick into, tight enough that the seam mostly closes. Below
    about 0.10 it starts fighting elephant's foot on the tab, so that is the floor.
    The slider also moved to 0.01 steps. It was 0.05 from a 0.1 minimum, so 0.12 was
    not a value anyone could have selected.
    Medium preset: 920 x 330 x 90, 30 mm flat top, 80 mm side taper. Worth knowing
    what it does before building on it -- 4.96 kg solid or 1.89 kg as a deck, 17.4
    degrees, and on a single 920 mm hump the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
    [bikeramp.scad, tile_00.stl, tile_01.stl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]
2026-08-17 Joinable ramp modules: up, flat and down
    Print a rise now, add a flat later, and have the two bolt together with a
    transition you cannot feel.
    The joint needed no new mechanism. xseamTabs places dovetails by span and local
    height, so two modules of the same width and end height produce identical tab
    patterns -- a module end is just a tile seam that has no neighbour yet. Rise
    ends with tabs at 55/165/275 across 330 mm and flat starts with sockets at
    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
    [bikeramp.scad]
2026-08-17 Join deck modules with a shared rib, and fix the triangulator that hid it
    Modularity was real on the solid path and cosmetic on the deck path, which is
    backwards -- at 90 mm tall the solid set is 8.2 kg and the deck 3.7, so the deck
    is the one anyone would print.
    Each module's base strips now stop with a half-mortise at the end face. Butt two
    modules and the halves make a whole mortise: one rib's feet drop in and span the
    seam, tying the modules together and carrying the end of both plywood sheets, so
    the surface stays flush across the joint. Both modules ship that rib and they
    are dimensionally identical -- use either, keep the spare. The channels butt and
    the shared rib holds them in line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
2026-08-17 Run dovetails further towards the toe
    On a 920 mm hill the centre seam had tabs from x=173 to 748, leaving 173 mm at
    each end with nothing holding the two halves together. Tabs were spaced evenly
    across the whole seam and the thin ones then discarded, so the end positions
    landed where the ramp is 4 mm thick, got dropped, and took their slot with them:
    the tab was lost and so was the space it would have occupied.
    Find the stretches thick enough to carry a tab first, then space tabs to the
    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
    [bikeramp.scad, tile_00.stl, tile_01.stl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]
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2026-08-21 One-plate module joint test
    module_up + module_flat + module_down at 80 x 40 mm, all three on one plate,
    about 317 g and 6.5 h.
    Small, not scaled. The dovetail is the production part at production size --
    12 mm deep, 26 mm tip, 0.12 mm per side -- and only the ramp around it is short.
    Scaling a module down 3x would take the clearance to 0.04 mm, under one
    extrusion width, so the joint would fuse and prove nothing. This is the same
    reasoning the original test plate was built on.
    At 80 mm wide each joint gets one dovetail rather than the three it gets at the
    330 mm working width, which makes it the harder test: all the load goes through
    the one.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
    [module_down.stl, module_flat.stl, module_up.stl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]
